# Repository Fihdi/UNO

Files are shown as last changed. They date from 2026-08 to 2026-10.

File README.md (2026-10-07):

# 8hp VCO/LFO

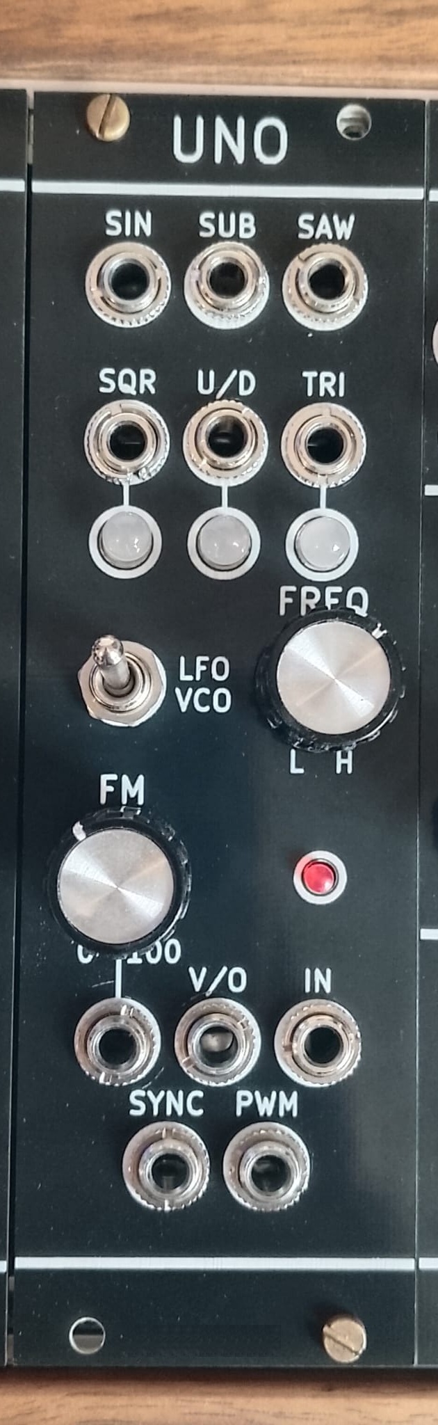
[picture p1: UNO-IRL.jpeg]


UNO (Universal Oscillator) is an all-purpose voltage controlled oscillator / LFO. The frequency range can be switched from low (**LFO** mode) to high (**VCO** mode).

The frequency of the oscillator can be set by the **FREQ** knob as well as the **V/O** input, **FM** input and **FM** knob. 

The **PWM** input can change the duty cycle of the **SQR** output. Its is possible to achieve 0% or 100% duty cycle, giving the user the ability to stop the oscillation of the **SQR** output.

The **SUB** output creates a square wave with half the frequency of the **SQR** signal, 

The **IN** input overrides the oscillator completely and turns UNO into a slew rate limiter. The Triangle output follows the **IN** input with the speed set by the **FREQ** knob as well as the **V/O** and **FM** CVs.

The **SYNC** input is a less extreme version of the **IN** input. Instead of overriding, it creates an average between the **SYNC** and the oscillator signal. By varying the strength of the **SYNC** signal it is possible to go from soft- to hard-synchronization.

The **U/D** (Up/Down) output is 5V when the **TRI** output is rising and -5V when **TRI** output is falling. NOTE when using UNO as a slew rate limiter: When the **TRI** output has reached the **IN** input, the **U/D** output starts to oscillate wildly.

**SIN** is a sinusoid version of **TRI**. The **SAW** output is twice the frequency of **TRI** and **SIN**.

Trimmers on the back of the module can be used to tune the volt per octave tracking and the shape of the sine output.

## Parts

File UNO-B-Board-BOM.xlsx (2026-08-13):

 |  |  | UNO B-Board BOM
Item # | *Designator | *Qty | Manufacturer | *Mfg Part # | Description / Value | *Package/Footprint | Type | Your Instructions / Notes
1 | C3 | 1 |  | C5137623 | 10n | Capacitor_SMD:C_1206_3216Metric
2 | C4,C5,C101,C102 | 4 |  | C9807 | 10u | Capacitor_SMD:C_1206_3216Metric
3 | C7 | 1 |  | C377070 | 1u | Capacitor_SMD:C_1206_3216Metric
4 | C103,C104 | 2 |  | C309030 | 100n | Capacitor_SMD:C_1206_3216Metric
5 | D2,D3,D4,D5,D12,D13 | 6 |  | C917117 | 4148 | Diode_SMD:D_SOD-323_HandSoldering
6 | J10 | 1 |  |  | Conn_02x05_Odd_Even | Connector_IDC:IDC-Header_2x05_P2.54mm_Vertical |  | DNP
7 | J16 | 1 |  |  | Conn_01x05_Pin | Connector_PinSocket_2.54mm:PinSocket_1x05_P2.54mm_Vertical |  | DNP
8 | J103 | 1 |  |  | Conn_01x04_Pin | Connector_PinHeader_2.54mm:PinHeader_1x04_P2.54mm_Vertical |  | DNP
9 | J104 | 1 |  |  | Conn_01x08_Pin | Connector_PinSocket_2.54mm:PinSocket_1x08_P2.54mm_Vertical |  | DNP
10 | Q1 | 1 |  | C475630 | BC847 | Package_TO_SOT_SMD:SOT-23
11 | Q2,Q3 | 2 |  | C148244 | BC857 | Package_TO_SOT_SMD:SOT-23
12 | R2,R3,R4,R11,R14,R18,R20,R23,R24,R27,R28,R32,R34 | 13 |  | C2907421 | 100k | Resistor_SMD:R_1206_3216Metric
13 | R6,R9,R12,R22,R31,R33,R101,R104 | 8 |  | C131398 | 1k | Resistor_SMD:R_1206_3216Metric
14 | R10 | 1 |  | C2907369 | 100R | Resistor_SMD:R_1206_3216Metric
15 | R13 | 1 |  | C4046839 | 56k | Resistor_SMD:R_1206_3216Metric
16 | R17,R19,R21,R25,R50 | 5 |  | C2907423 | 10k | Resistor_SMD:R_1206_3216Metric
17 | R29,R30,R35,R48 | 4 |  | C2907507 | 47k | Resistor_SMD:R_1206_3216Metric
18 | R102,R103 | 2 |  | C4299795 | 6k2 | Resistor_SMD:R_1206_3216Metric
19 | RV2,RV3 | 2 |  |  | 100k | Potentiometer_THT:Potentiometer_Bourns_3296W_Vertical |  | DNP
20 | U3 | 1 |  | C174050 | LM13700 | Package_SO:SOIC-16_3.9x9.9mm_P1.27mm
21 | U4,U5 | 2 |  | C12594 | TL074 | Package_SO:SOIC-14_3.9x8.7mm_P1.27mm
22 | U7 | 1 |  | C353974 | 4040 | Package_SO:SOIC-16_3.9x9.9mm_P1.27mm
23 | U101 | 1 |  | C51466 | LM317_SOT-223 | Package_TO_SOT_SMD:SOT-223-3_TabPin2
24 | U102 | 1 |  | C19267471 | LM337_SOT223 | Package_TO_SOT_SMD:SOT-223-3_TabPin2
25 | U103 | 1 |  | C67473 | TL072 | Package_SO:SOIC-8_3.9x4.9mm_P1.27mm
Need a quick and accurante quote? Need an efficient production? Please read SMT Ordering Necessary Files & Info in 1 minute. Thank you very much!
Click for Instructions on How to Create a BOM (https://www.pcbway.com/blog/PCB_Assembly/How_to_Build_a_BOM__Bill_Of_Materials_.html)

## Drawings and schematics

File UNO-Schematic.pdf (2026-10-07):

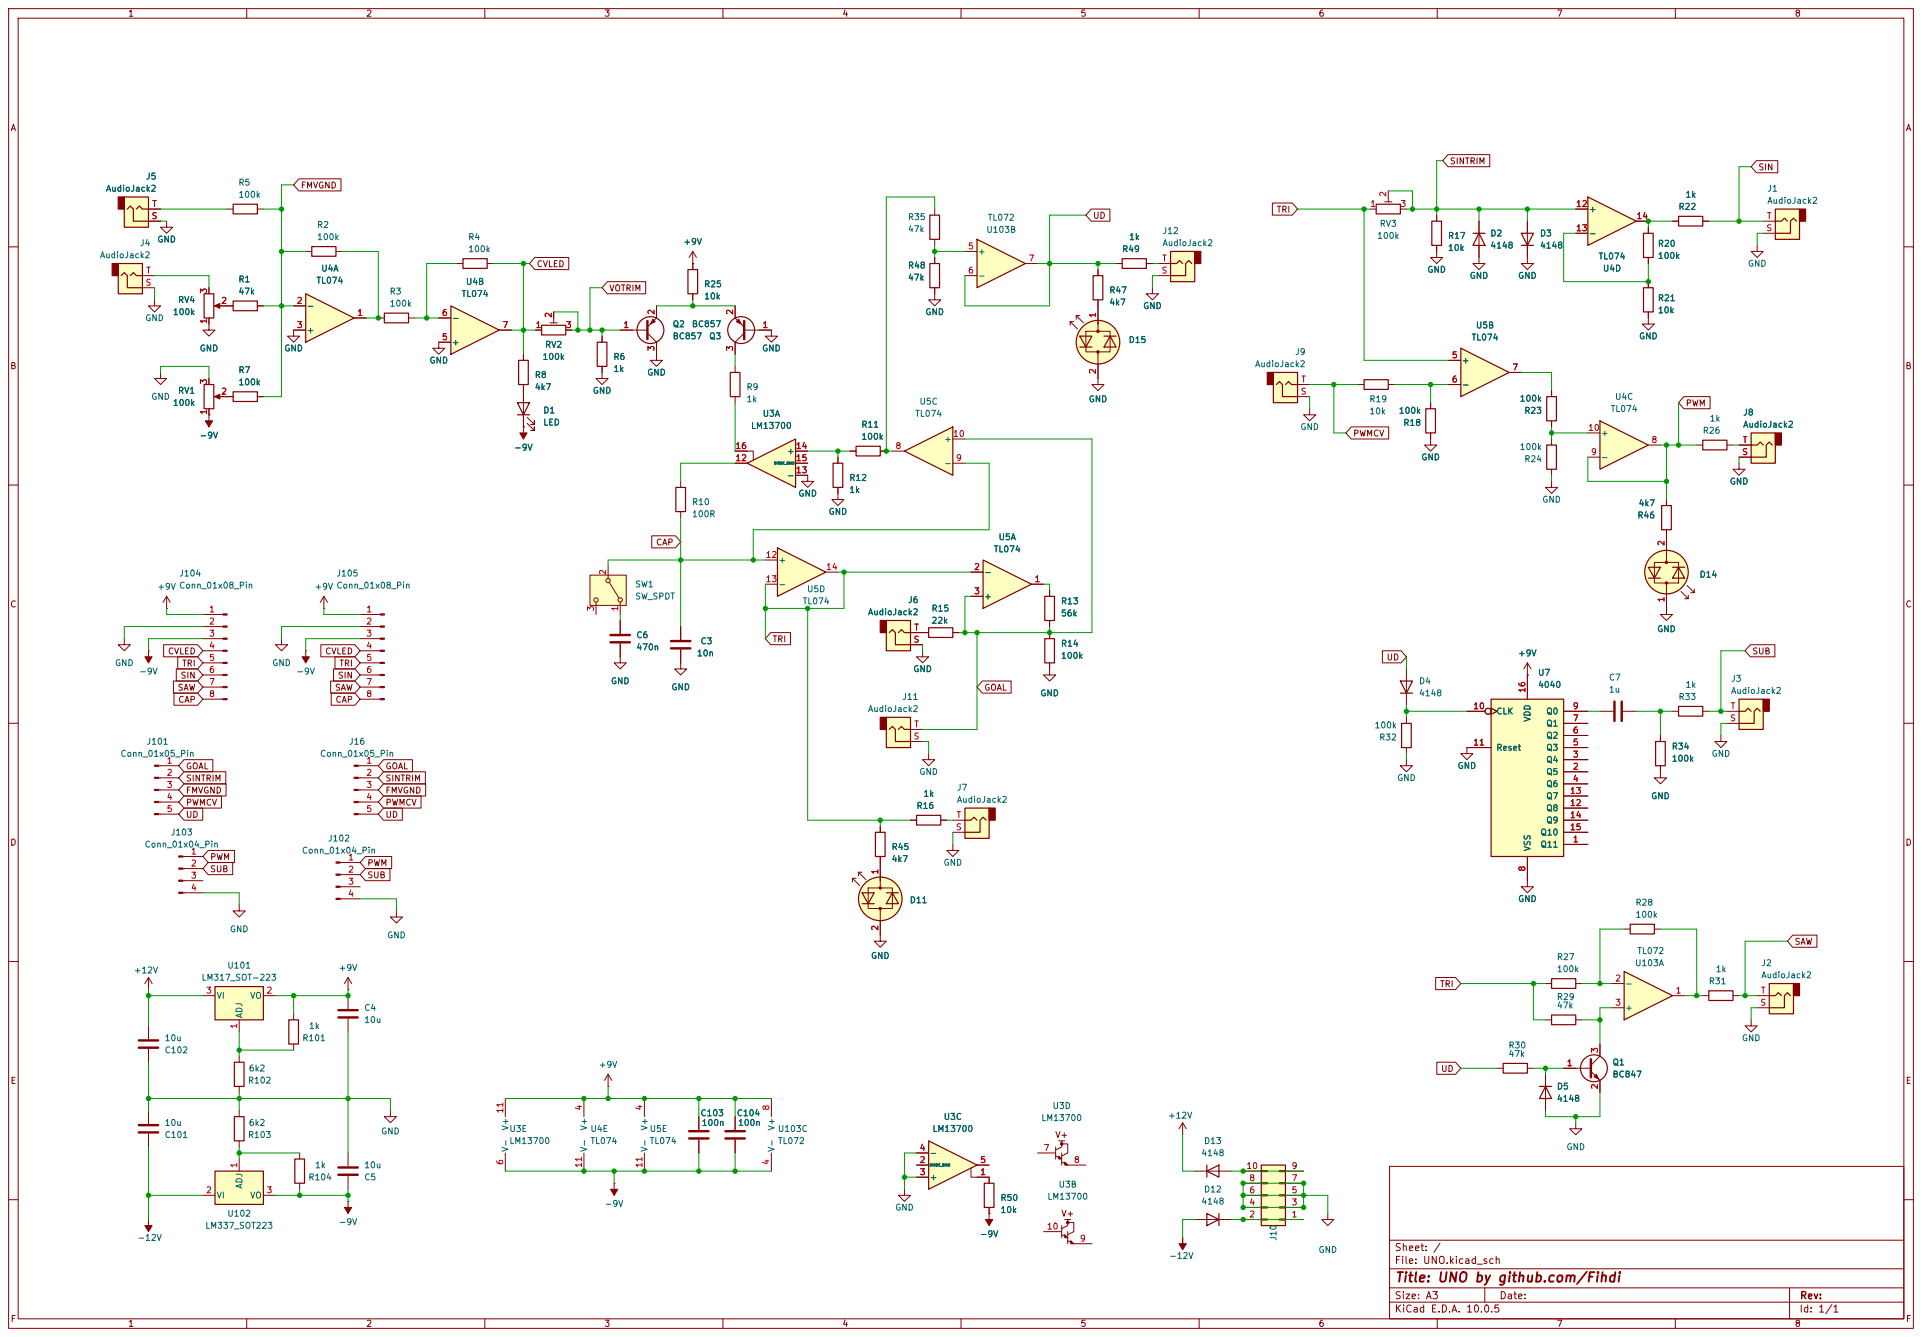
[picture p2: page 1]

8 Q0 9 CLK 10 Reset 11 Q8 12 Q7 13 Q9 14 Q10 15 VDD 16 GND +9V R46

File: UNO.kicad_sch
Title: UNO by github.com/Fihdi

Size: A3 | Rev: | F Date:
KiCad E.D.A. 10.0.5 | Id: 1/1

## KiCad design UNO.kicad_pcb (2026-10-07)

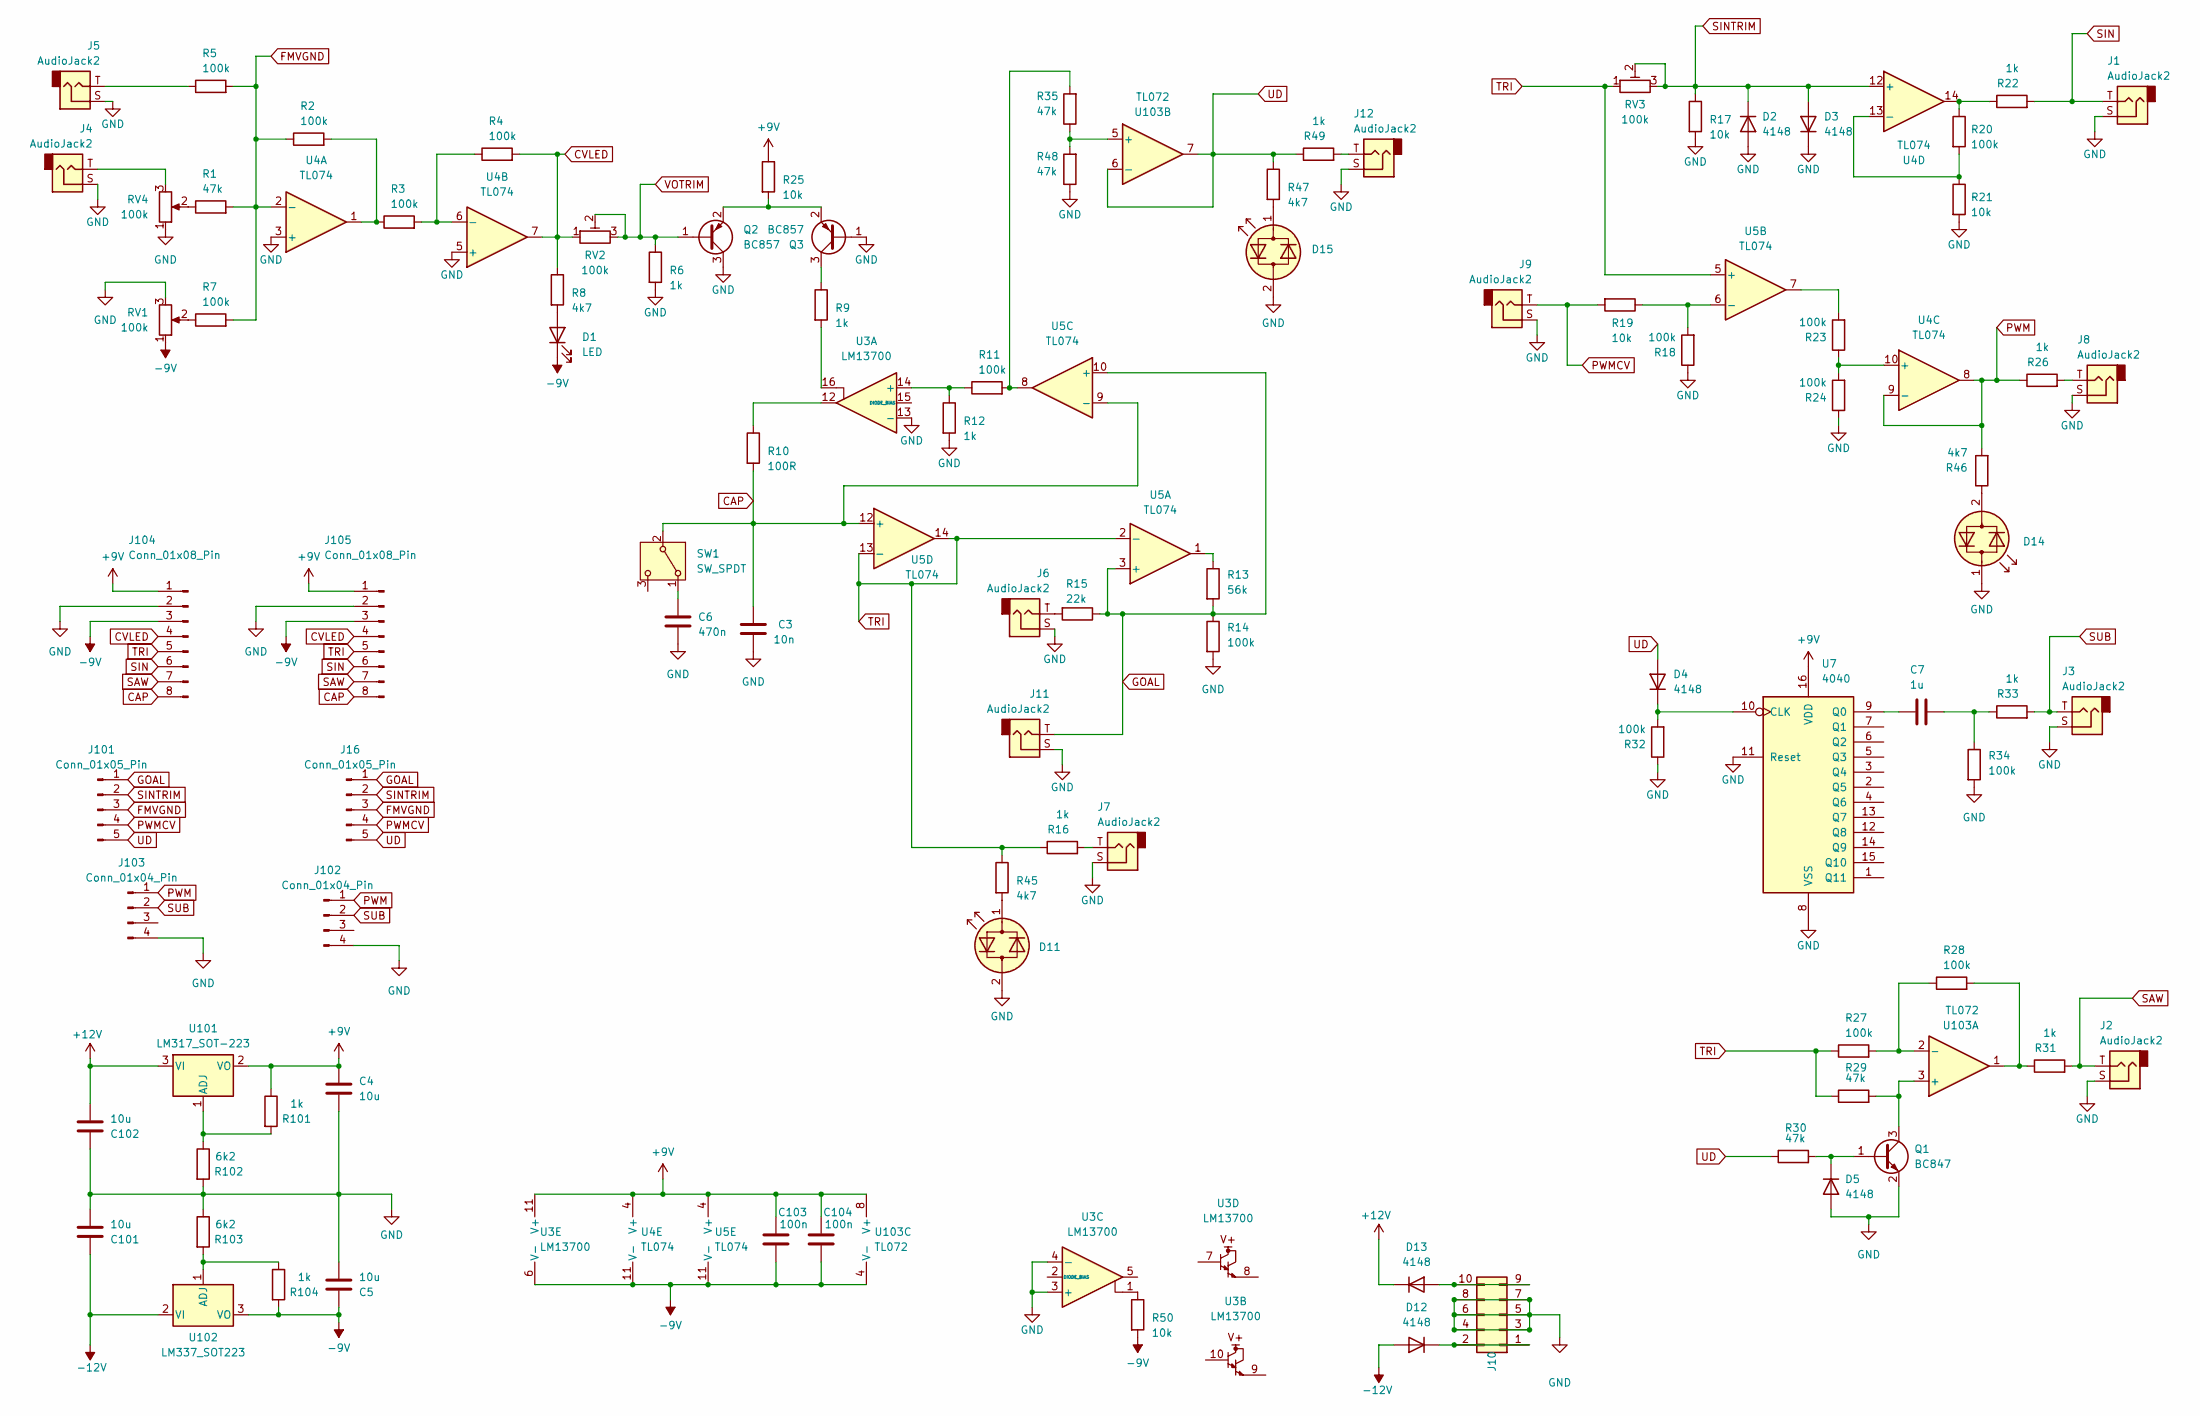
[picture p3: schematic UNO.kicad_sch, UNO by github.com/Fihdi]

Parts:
C3: 10n; C_1206_3216Metric
C4, C5, C101, C102: 10u; C_1206_3216Metric
C6: 470n; C_1206_3216Metric
C7: 1u; C_1206_3216Metric
C103, C104: 100n; C_1206_3216Metric
D1: LED; LED_D3.0mm
D2, D3, D4, D5, D12, D13: 4148; D_SOD-323_HandSoldering
D11, D14, D15: LED_Dual_Bidirectional; LED_D5.0mm
J1, J2, J3, J4, J5, J6, J7, J8, J9, J11, J12: AudioJack2; MonoTRS
J10: Conn_02x05_Odd_Even; IDC-Header_2x05_P2.54mm_Vertical
J16, J101: Conn_01x05_Pin; PinSocket_1x05_P2.54mm_Vertical
J102, J103: Conn_01x04_Pin; PinHeader_1x04_P2.54mm_Vertical
J104, J105: Conn_01x08_Pin; PinSocket_1x08_P2.54mm_Vertical
Q1: BC847; SOT-23
Q2, Q3: BC857; SOT-23
R1, R29, R30, R35, R48: 47k; R_1206_3216Metric
R2, R3, R4, R5, R7, R11, R14, R18, R20, R23, R24, R27, R28, R32, R34: 100k; R_1206_3216Metric
R6, R9, R12, R16, R22, R26, R31, R33, R49, R101, R104: 1k; R_1206_3216Metric
R8, R45, R46, R47: 4k7; R_1206_3216Metric
R10: 100R; R_1206_3216Metric
R13: 56k; R_1206_3216Metric
R15: 22k; R_1206_3216Metric
R17, R19, R21, R25, R50: 10k; R_1206_3216Metric
R102, R103: 6k2; R_1206_3216Metric
RV1, RV4: 100k; Potentiometer_Alpha_RD901F-40-00D_Single_Vertical
RV2, RV3: 100k; Potentiometer_Bourns_3296W_Vertical
SW1: SW_SPDT; Switch
U3: LM13700; SOIC-16_3.9x9.9mm_P1.27mm
U4, U5: TL074; SOIC-14_3.9x8.7mm_P1.27mm
U7: 4040; SOIC-16_3.9x9.9mm_P1.27mm
U101: LM317_SOT-223; SOT-223-3_TabPin2
U102: LM337_SOT223; SOT-223-3_TabPin2
U103: TL072; SOIC-8_3.9x4.9mm_P1.27mm

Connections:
+9V: C4.1, C103.1, C104.1, J104.1, J105.1, R25.1, R101.1, U3.11 (V+), U4.4 (V+), U5.4 (V+), U7.16 (VDD), U101.2 (VO), U103.8 (V+)
+12V: C102.2, D13.1 (K), U101.3 (VI)
-9V: C5.1, C103.2, C104.2, D1.1 (K), J104.3, J105.3, R50.2, R104.2, RV1.1, U3.6 (V-), U4.11 (V-), U5.11 (V-), U102.3 (VO), U103.4 (V-)
-12V: C101.1, D12.2 (A), U102.2 (VI)
CAP: C3.1, J104.8, J105.8, R10.2, SW1.2 (B), U5.9 (-), U5.12 (+)
CVLED: J104.4, J105.4, R4.2, R8.1, RV2.1, U4.7
FMVGND: J16.3, J101.3, R1.2, R2.1, R5.2, R7.2, U4.2 (-)
GND: C3.2, C4.2, C5.2, C6.2, C101.2, C102.1, D2.2 (A), D3.1 (K), D5.2 (A), D11.2 (AK), D14.1 (KA), D15.2 (AK), J1.S, J2.S, J3.S, J4.S, J5.S, J6.S, J7.S, J8.S, J9.S, J10.3, J10.4, J10.5, J10.6, J10.7, J10.8, J11.S, J12.S, J102.4, J103.4, J104.2, J105.2, Q1.2 (E), Q2.3 (C), Q3.1 (B), R6.2, R12.2, R14.2, R17.2, R18.1, R21.2, R24.1, R32.1, R34.2, R48.1, R102.2, R103.1, RV1.3, RV4.1, U3.3 (+), U3.4 (-), U3.13 (-), U4.3 (+), U4.5 (+), U7.8 (VSS), U7.11 (Reset)
GOAL: J11.T, J16.1, J101.1, R13.2, R14.1, R15.1, U5.3 (+), U5.10 (+)
unnamed: C7.2, R33.1, R34.1
unnamed: D1.2 (A), R8.2
unnamed: D4.1 (K), R32.2, U7.10 (CLK)
unnamed: D5.1 (K), Q1.1 (B), R30.2
unnamed: D11.1 (KA), R45.2
unnamed: D12.1 (K), J10.1, J10.2
unnamed: D13.2 (A), J10.9, J10.10
unnamed: D14.2 (AK), R46.1
unnamed: D15.1 (KA), R47.2
unnamed: J4.T, RV4.3
unnamed: J5.T, R5.1
unnamed: J6.T, R15.2
unnamed: J7.T, R16.2
unnamed: J8.T, R26.2
unnamed: J12.T, R49.2
unnamed: Q1.3 (C), R29.2, U103.3 (+)
unnamed: Q2.2 (E), Q3.2 (E), R25.2
unnamed: Q3.3 (C), R9.1
unnamed: R1.1, RV4.2
unnamed: R2.2, R3.1, U4.1
unnamed: R7.1, RV1.2
unnamed: R9.2, U3.16
unnamed: R10.1, U3.12
unnamed: R11.2, R35.2, U5.8
unnamed: R13.1, U5.1
unnamed: R20.1, R22.1, U4.14
unnamed: R23.2, U5.7
unnamed: R28.2, R31.1, U103.1
unnamed: R50.1, U3.1
unnamed: C6.1, SW1.1 (A)
unnamed: R11.1, R12.1, U3.14 (+)
unnamed: R3.2, R4.1, U4.6 (-)
unnamed: R23.1, R24.2, U4.10 (+)
unnamed: R20.2, R21.1, U4.13 (-)
unnamed: R18.2, R19.1, U5.6 (-)
unnamed: C7.1, U7.9 (Q0)
unnamed: R101.2, R102.1, U101.1 (ADJ)
unnamed: R103.2, R104.1, U102.1 (ADJ)
unnamed: R27.2, R28.1, U103.2 (-)
unnamed: R35.1, R48.2, U103.5 (+)
PWM: J102.1, J103.1, R26.1, R46.2, U4.8, U4.9 (-)
PWMCV: J9.T, J16.4, J101.4, R19.2
SAW: J2.T, J104.7, J105.7, R31.2
SIN: J1.T, J104.6, J105.6, R22.2
SINTRIM: D2.1 (K), D3.2 (A), J16.2, J101.2, R17.1, RV3.2, RV3.3, U4.12 (+)
SUB: J3.T, J102.2, J103.2, R33.2
TRI: J104.5, J105.5, R16.1, R27.1, R29.1, R45.1, RV3.1, U5.2 (-), U5.5 (+), U5.13 (-), U5.14
UD: D4.2 (A), J16.5, J101.5, R30.1, R47.1, R49.1, U103.6 (-), U103.7
VOTRIM: Q2.1 (B), R6.1, RV2.2, RV2.3

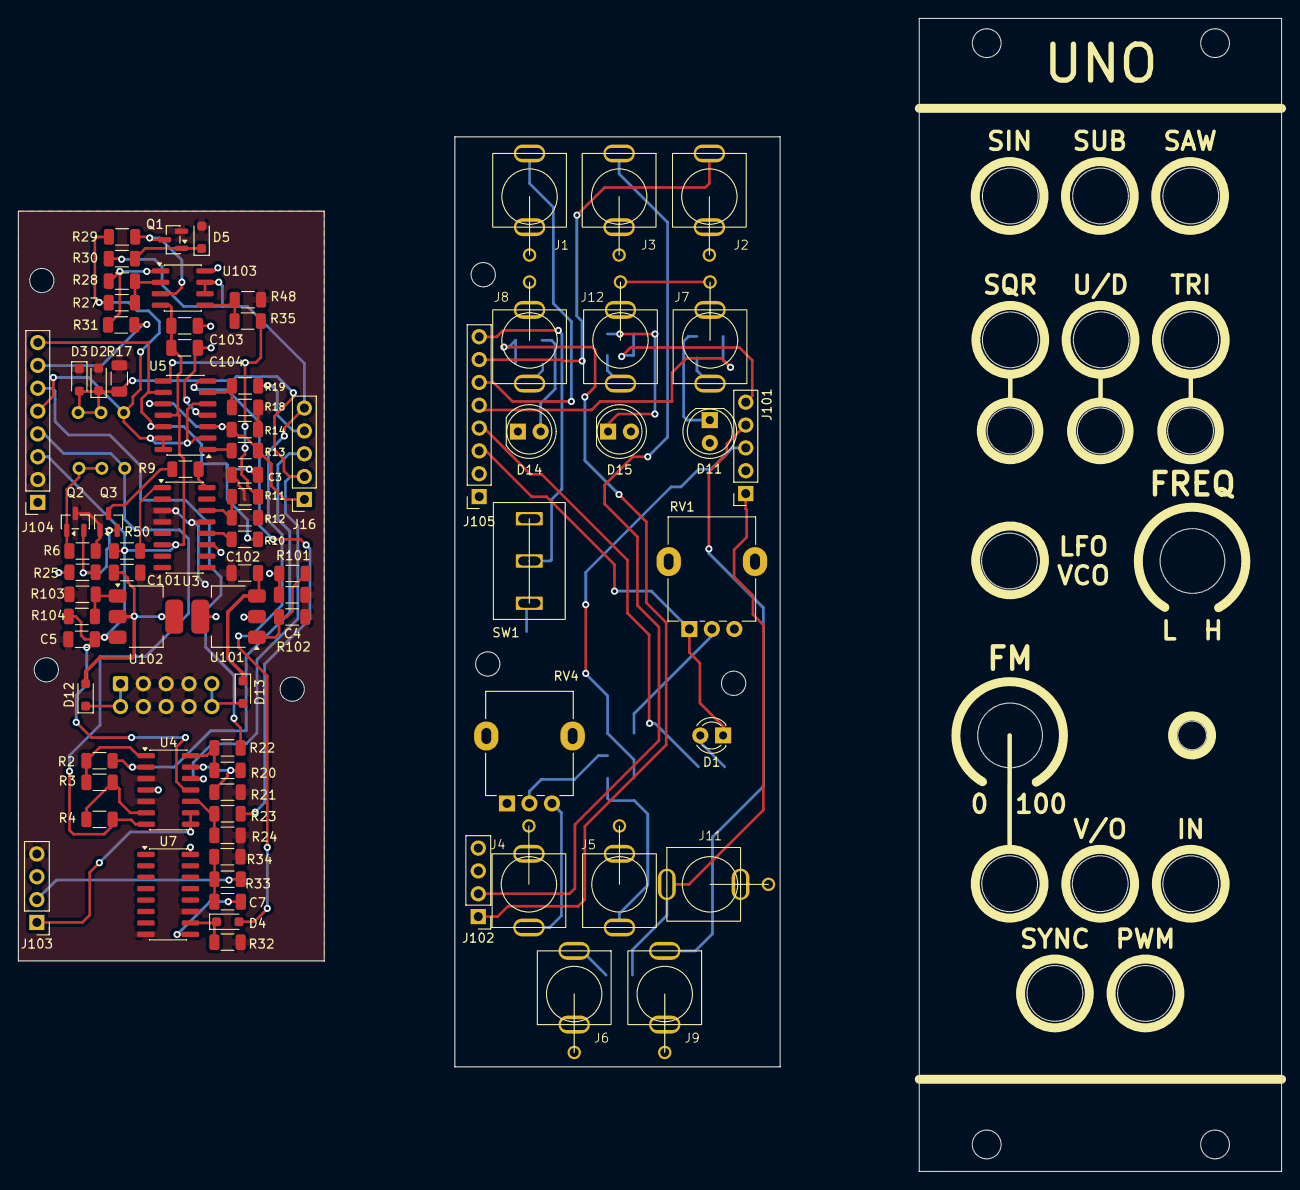
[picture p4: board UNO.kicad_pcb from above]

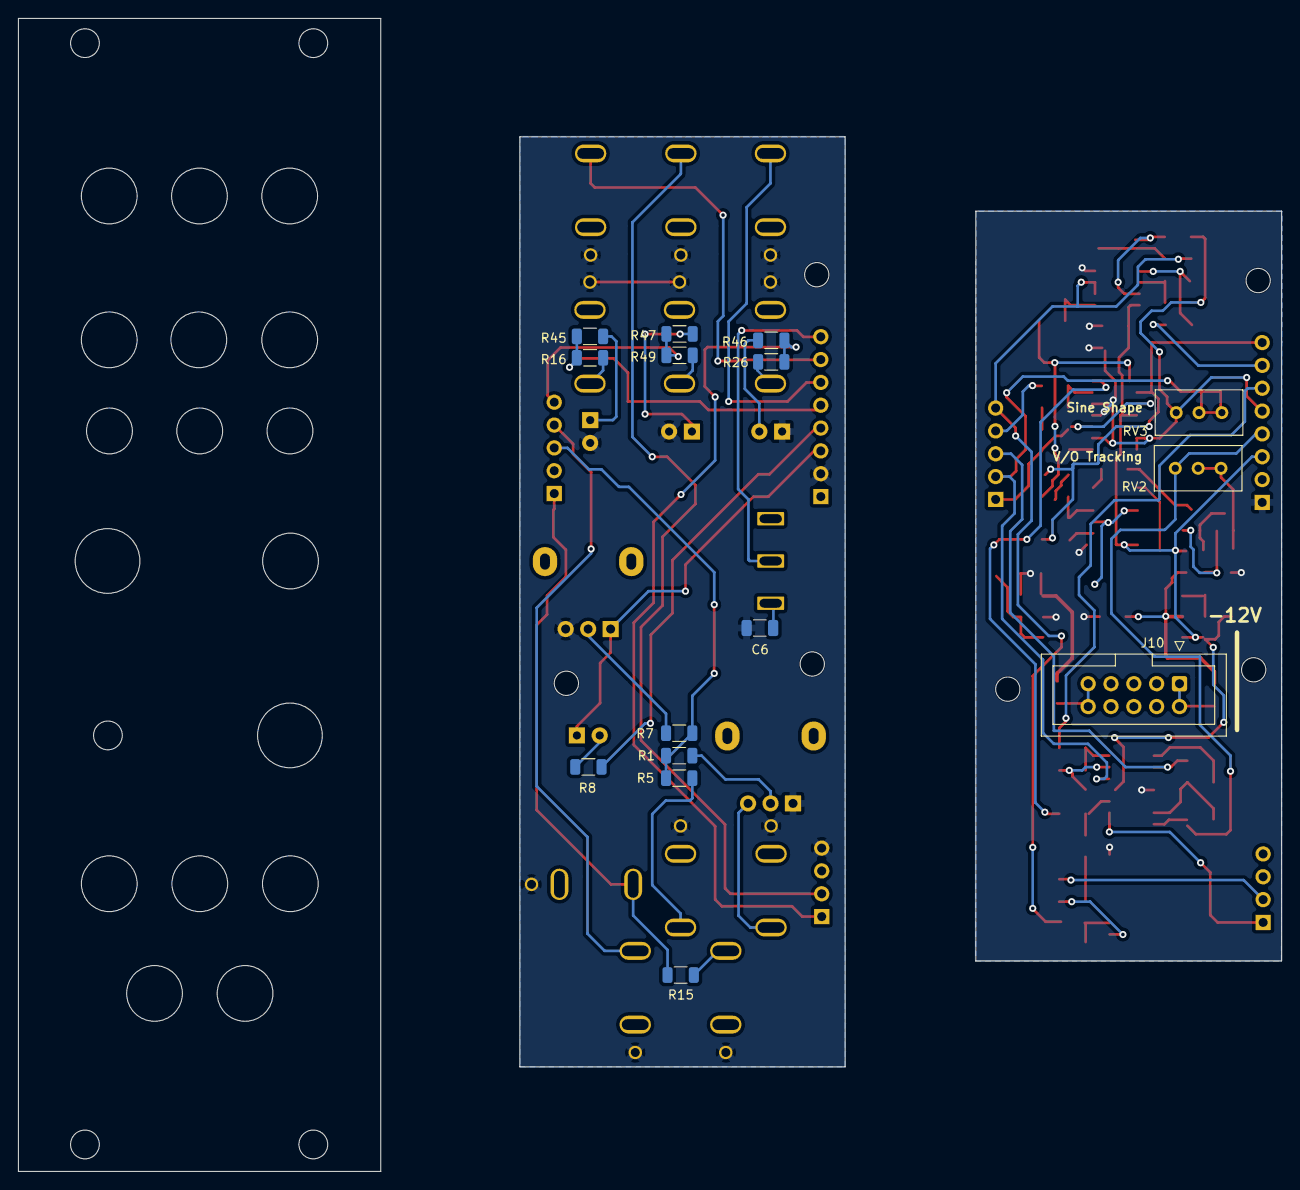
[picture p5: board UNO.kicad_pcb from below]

Board: 2 copper layers, 140.5 x 128.2 mm, 97 parts (15 on the bottom side), 58 nets.

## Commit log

2026-07-08 Minor schematic and B-Board update
    The schmitt trigger output (-11V to 11V output) was fed to the comparator directly. -11V to an TL074 comparator can result in phase reversal issues. Signal goes from the schmitt trigger voltage divider to the comparator now.
    [UNO.kicad_pcb, UNO.kicad_sch]
2026-10-07 Corrected FREQ knob polarity
    [UNO.kicad_pcb, UNO.kicad_sch]
